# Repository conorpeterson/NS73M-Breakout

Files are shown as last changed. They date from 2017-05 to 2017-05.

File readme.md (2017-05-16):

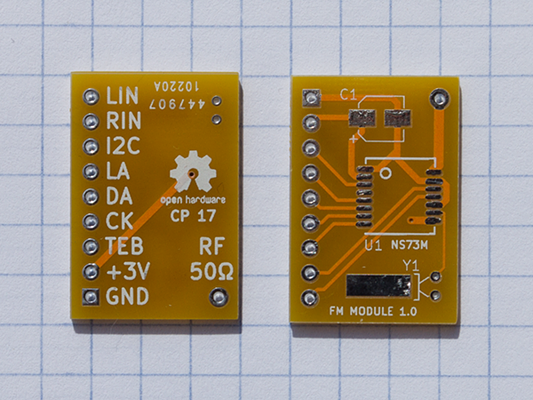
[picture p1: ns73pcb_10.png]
PCB Photo

# NS73M-Breakout
2017 Conor Peterson (conor.p.peterson@gmail.com)

License: Creative Commons Attribution International 4.0 (CC-BY-4.0)

This is a breakout board for the Niigata Seimitsu NS73M FM transmitter chip. It
is based on a now-discontinued board formerly available from Sparkfun. Besides
the transmitter itself, there are pads for a crystal and SMT electrolytic
capacitor. Build note: the solder pad under the crystal body is intended to help
mechanically secure the package. 

Dimensions: 25mm x 17mm

Layers: 2

## Bill of Materials
```
| Ref | Spec          | Manu               | Manu Part        | Digikey #    |
| C1  | 22uF 10v      | Panasonic          | EEE-FK1A220R     | PCE3774CT-ND |
| Y1  | 32.768 kHz    | Citizen Finedevice | CFS-20632768DZBB | 300-8301-ND  |
| U1  | RF Xmitter    | Niigata Seimitsu   | NS73M            | N/A          |
| P1  | .100" x 9 pos | Sullins Connector  | PEC09SFAN        | S1212E-09-ND |
```

_Note: for runs of 5 or more, substitute P1 for 40-position breakway header
(e.g. Sullins Connector Solutions PRPC040SAAN-RC, Digikey #S1011EC-40-ND or similar)_

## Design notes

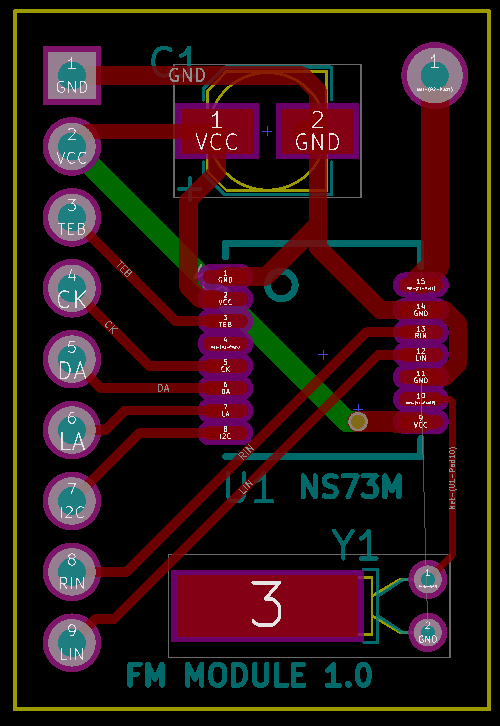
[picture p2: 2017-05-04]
pcb-plot.png

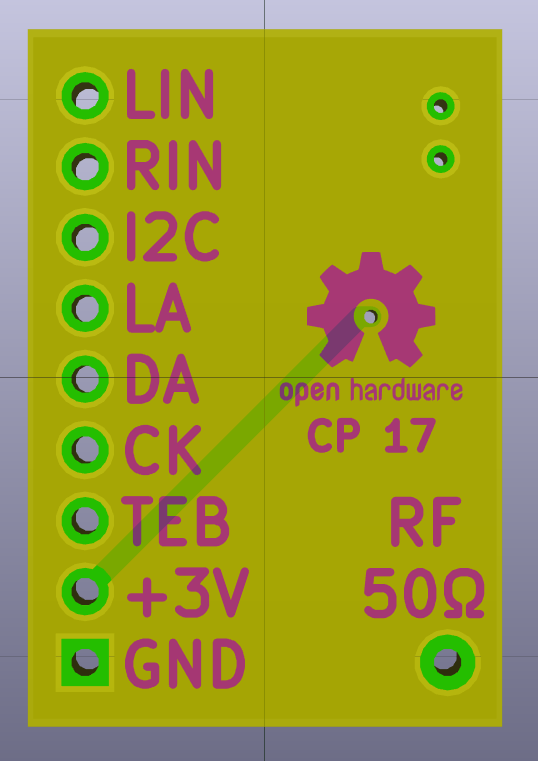
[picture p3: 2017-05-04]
pcb-reverse.png

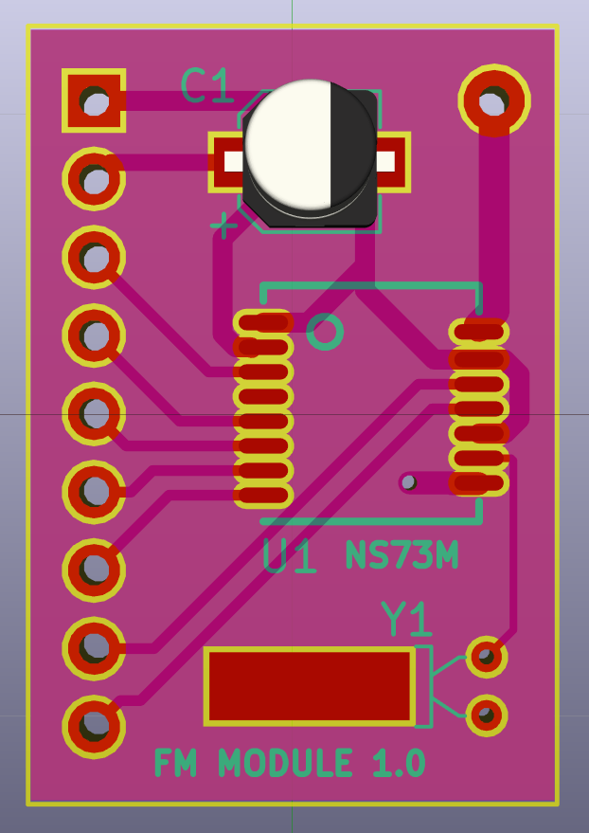
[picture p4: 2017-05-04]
pcb-front.png

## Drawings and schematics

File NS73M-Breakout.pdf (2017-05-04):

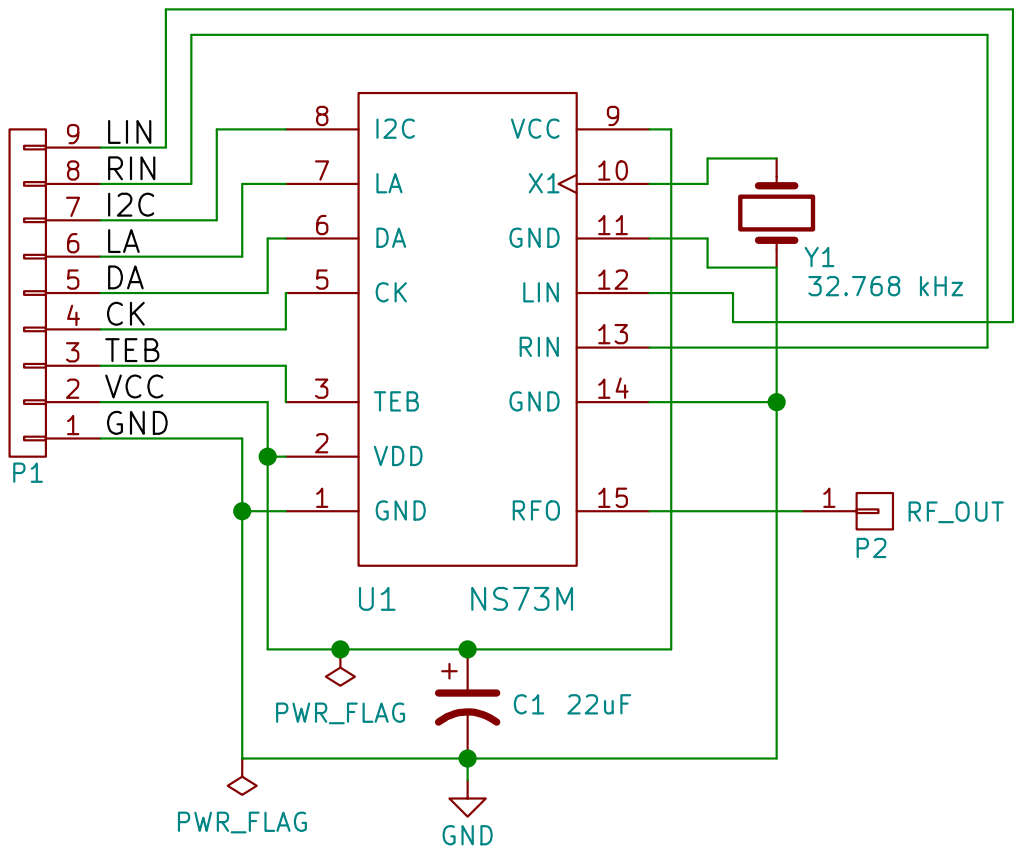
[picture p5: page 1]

conor.p.peterson@gmail.com
Id: 1/1 Title: NS73M-Breakout File: NS73M-Breakout.sch Sheet: / Conor Peterson

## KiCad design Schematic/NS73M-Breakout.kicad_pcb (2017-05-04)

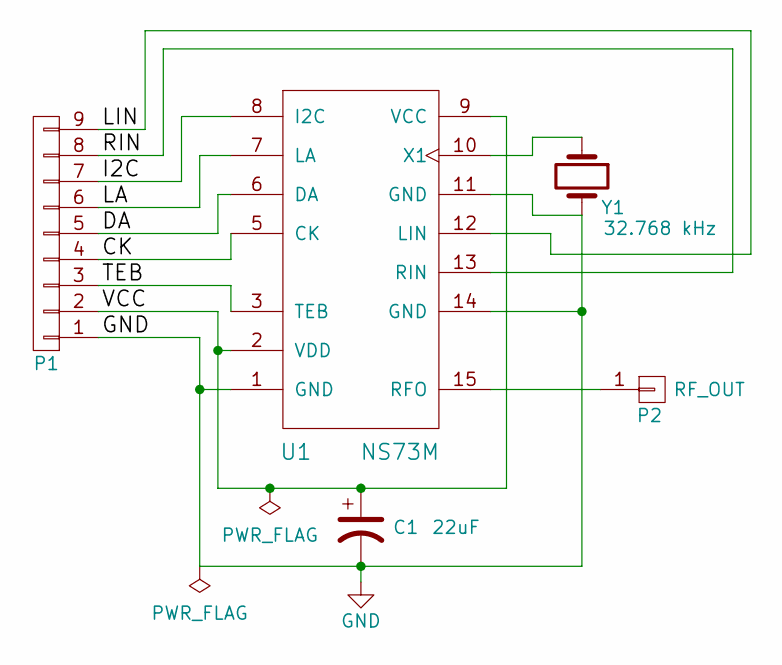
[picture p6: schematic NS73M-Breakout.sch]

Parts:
C1: 22uF; CP_Elec_4x4.5
P1: HEADER; Pin_Header_Angled_1x09_Pitch2.54mm_Reverse
P2: RF_OUT; Pin_Header_Angled_1x01_Pitch2.54mm
U1: NS73M; NS73M-DFN
Y1: 32.768 kHz; Crystal_C26-LF_d2.1mm_l6.5mm_Horizontal_1EP_style1

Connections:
/CK: P1.4, U1.5 (CK)
/DA: P1.5, U1.6 (DA)
/I2C: P1.7, U1.8 (I2C)
/LA: P1.6, U1.7 (LA)
/LIN: P1.9, U1.12 (LIN)
/RIN: P1.8, U1.13 (RIN)
/TEB: P1.3, U1.3 (TEB)
/VCC: C1.1, P1.2, U1.2 (VDD), U1.9 (VCC)
GND: C1.2, P1.1, U1.1 (GND), U1.11 (GND), U1.14 (GND), Y1.2
unnamed: P2.1, U1.15 (RFO)
unnamed: U1.10 (X1), Y1.1

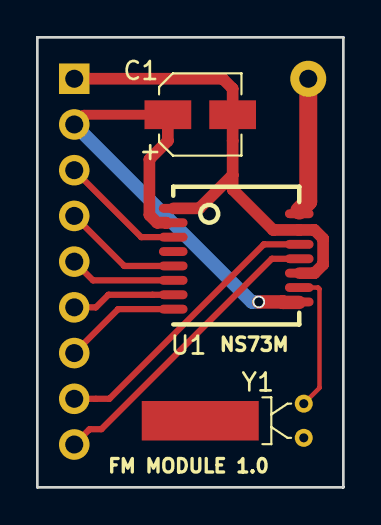
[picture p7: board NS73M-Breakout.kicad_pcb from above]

Board: 2 copper layers, 17.0 x 25.0 mm, 5 parts (0 on the bottom side), 11 nets.

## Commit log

2017-05-03 Initial commit - basic schematic with three components
    [NS73M-Breakout.kicad_pcb, NS73M-Breakout.sch]
2017-05-03 Power flags, schematic passes ERC
    [NS73M-Breakout.sch]
2017-05-03 First revision of PCB including gerbers
    [NS73M-Breakout-B.Cu.gbl, NS73M-Breakout-B.Mask.gbs, NS73M-Breakout-B.SilkS.gbo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]
2017-05-04 Cleaned up schematic, gerber packages, added license and PCB screencaps
    [NS73M-Breakout.kicad_pcb, NS73M-Breakout.sch]
2017-05-16 Photos of PCB in updated readme
